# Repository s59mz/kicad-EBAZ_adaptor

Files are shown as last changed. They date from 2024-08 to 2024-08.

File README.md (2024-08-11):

# ebaz_adaptor
Adapter board from the EBAZ FPGA board to multiple Alinx modules and PMOD interfaces

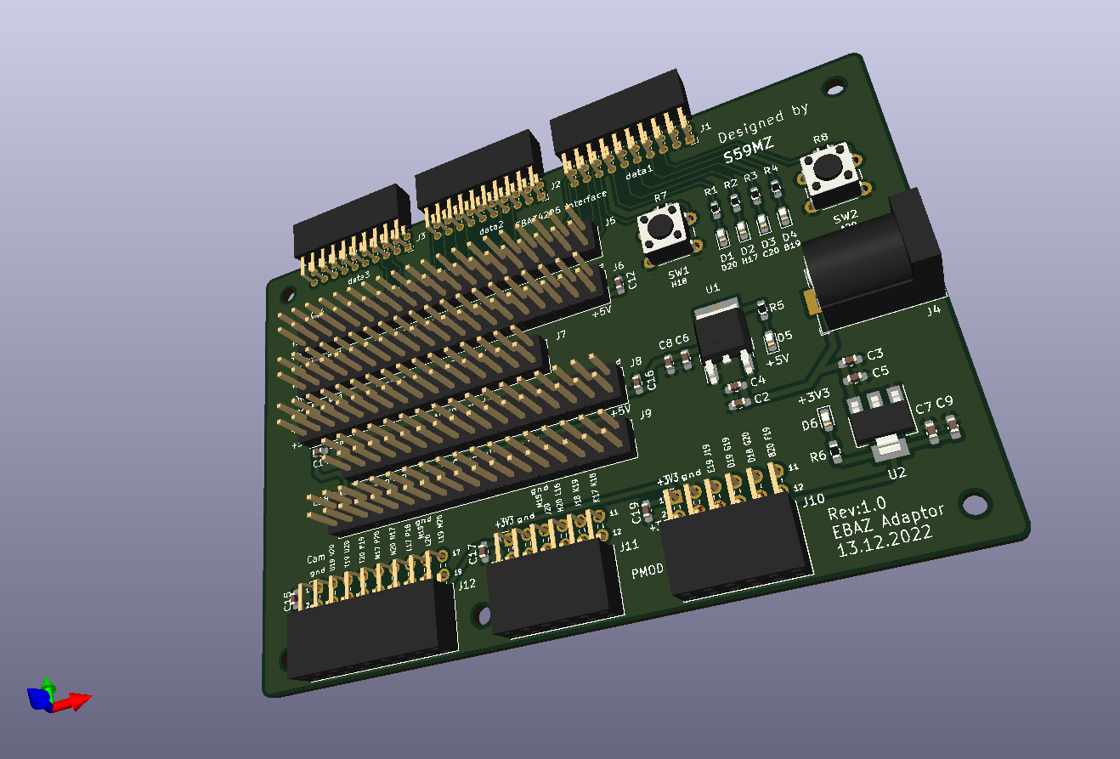
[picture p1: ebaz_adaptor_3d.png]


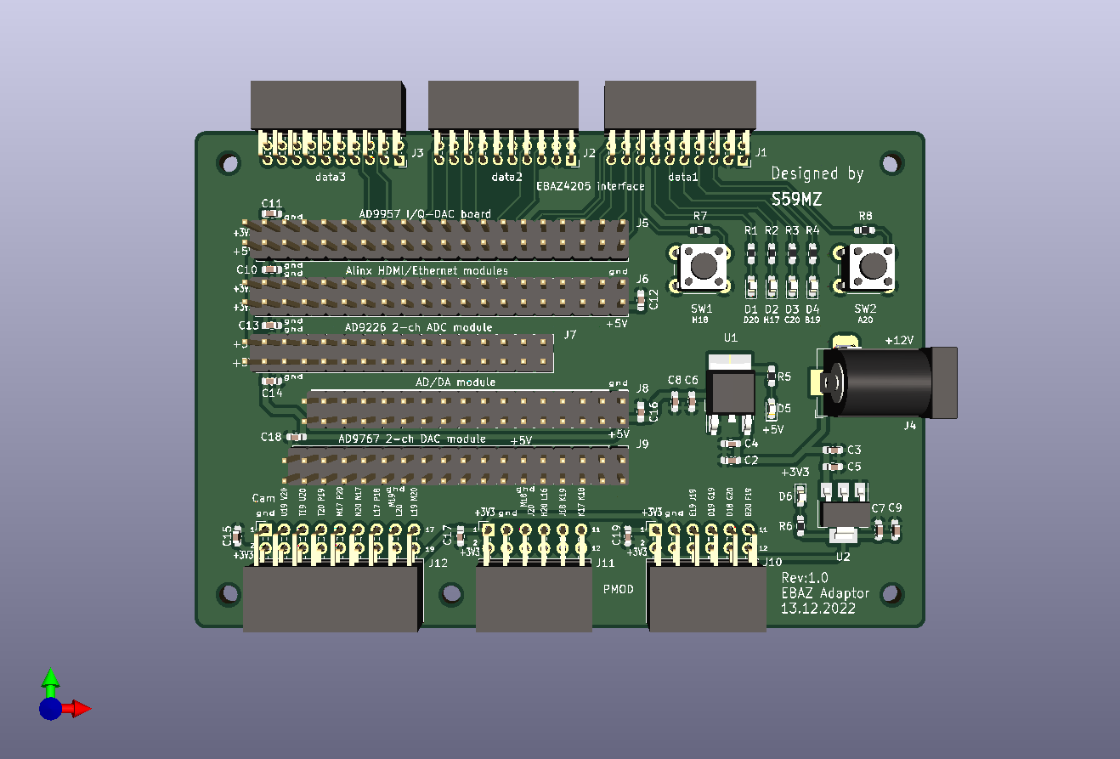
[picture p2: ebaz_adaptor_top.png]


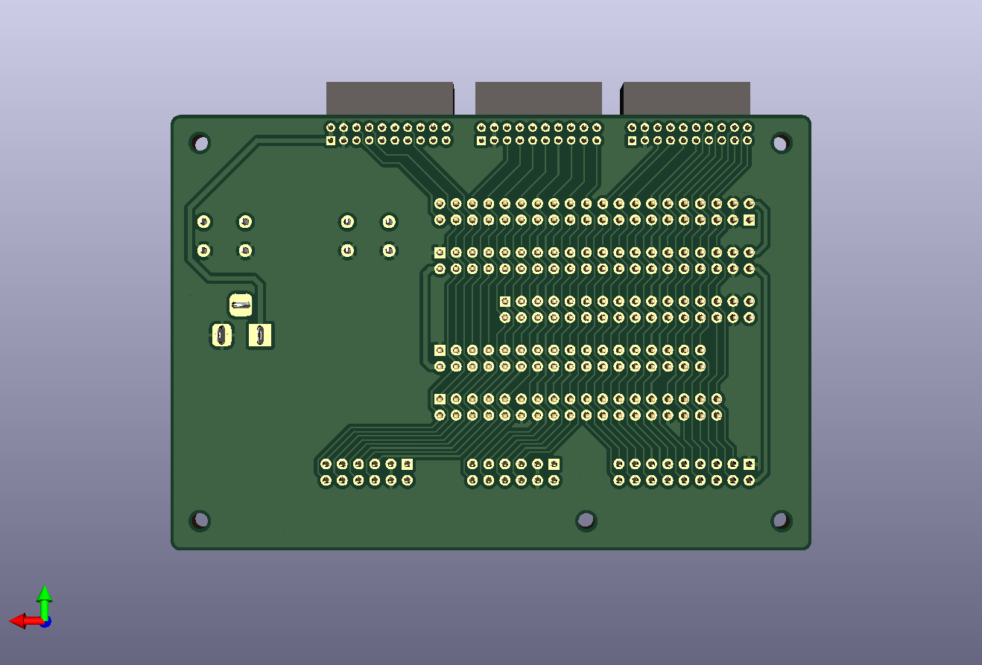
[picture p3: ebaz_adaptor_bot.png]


Schematic:
[ebaz_adaptor.pdf](ebaz_adaptor.pdf)

BOM:
[ebaz_adaptor.csv](ebaz_adaptor.csv)

Gerbers:
[gerbers.zip](https://github.com/s59mz/kicad-EBAZ_adaptor/raw/main/gerbers.zip)

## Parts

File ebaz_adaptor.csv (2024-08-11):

Comment | Designator | Footprint | LCSC
10u | C2,C3,C6,C7,C10,C11 | Capacitor_SMD:C_0603_1608Metric_Pad1.08x0.95mm_HandSolder
100n | C4,C5,C8,C9,C12,C13,C14,C15,C16,C17,C18,C19 | Capacitor_SMD:C_0603_1608Metric_Pad1.08x0.95mm_HandSolder
red | D1,D2,D3,D4,D5 | LED_SMD:LED_0603_1608Metric_Pad1.05x0.95mm_HandSolder
green | D6 | LED_SMD:LED_0603_1608Metric_Pad1.05x0.95mm_HandSolder
2.5 | H1,H2,H3,H4,H5 | MountingHole:MountingHole_2.5mm
data-1 | J1 | connectors:PinSocket_2x10_P2.00mm_Horizontal
pmod 1 | J10 | Connector_PinSocket_2.54mm:PinSocket_2x06_P2.54mm_Horizontal
pmod 2 | J11 | Connector_PinSocket_2.54mm:PinSocket_2x06_P2.54mm_Horizontal
camera | J12 | Connector_PinSocket_2.54mm:PinSocket_2x09_P2.54mm_Horizontal
data-2 | J2 | connectors:PinSocket_2x10_P2.00mm_Horizontal
data-3 | J3 | connectors:PinSocket_2x10_P2.00mm_Horizontal
+12V pwr | J4 | Connector_BarrelJack:BarrelJack_Horizontal
Z-Turn Extension | J5 | Connector_PinHeader_2.54mm:PinHeader_2x20_P2.54mm_Vertical
Alinx HDMI/ETH module | J6 | Connector_PinHeader_2.54mm:PinHeader_2x20_P2.54mm_Vertical
ADC module 2-ch | J7 | Connector_PinHeader_2.54mm:PinHeader_2x16_P2.54mm_Vertical
AD DA module | J8 | Connector_PinHeader_2.54mm:PinHeader_2x17_P2.54mm_Vertical
DAC module 2-ch | J9 | Connector_PinHeader_2.54mm:PinHeader_2x18_P2.54mm_Vertical
470E | R1,R2,R3,R4,R6 | Resistor_SMD:R_0603_1608Metric_Pad0.98x0.95mm_HandSolder
1k | R5,R7,R8 | Resistor_SMD:R_0603_1608Metric_Pad0.98x0.95mm_HandSolder
SW_Push | SW1,SW2 | Button_Switch_THT:SW_PUSH_6mm
AMS1117-5.0 | U1 | Package_TO_SOT_SMD:TO-252-2
AMS1117-3.3 | U2 | Package_TO_SOT_SMD:SOT-223-3_TabPin2

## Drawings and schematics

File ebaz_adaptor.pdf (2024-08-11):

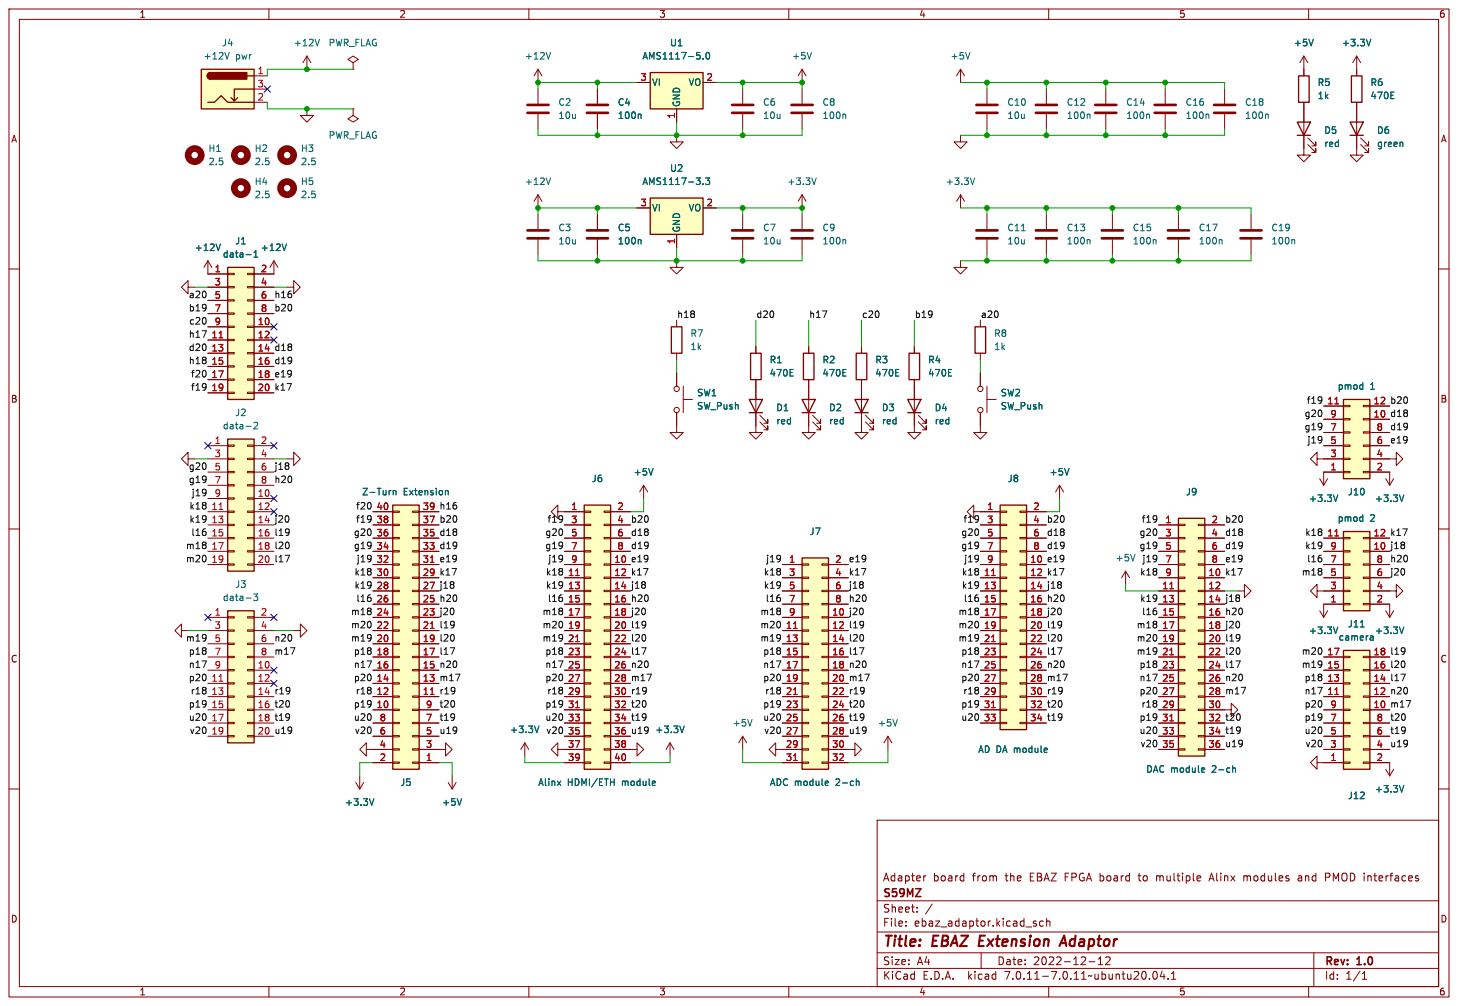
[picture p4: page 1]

J6 Alinx HDMI/ETH module

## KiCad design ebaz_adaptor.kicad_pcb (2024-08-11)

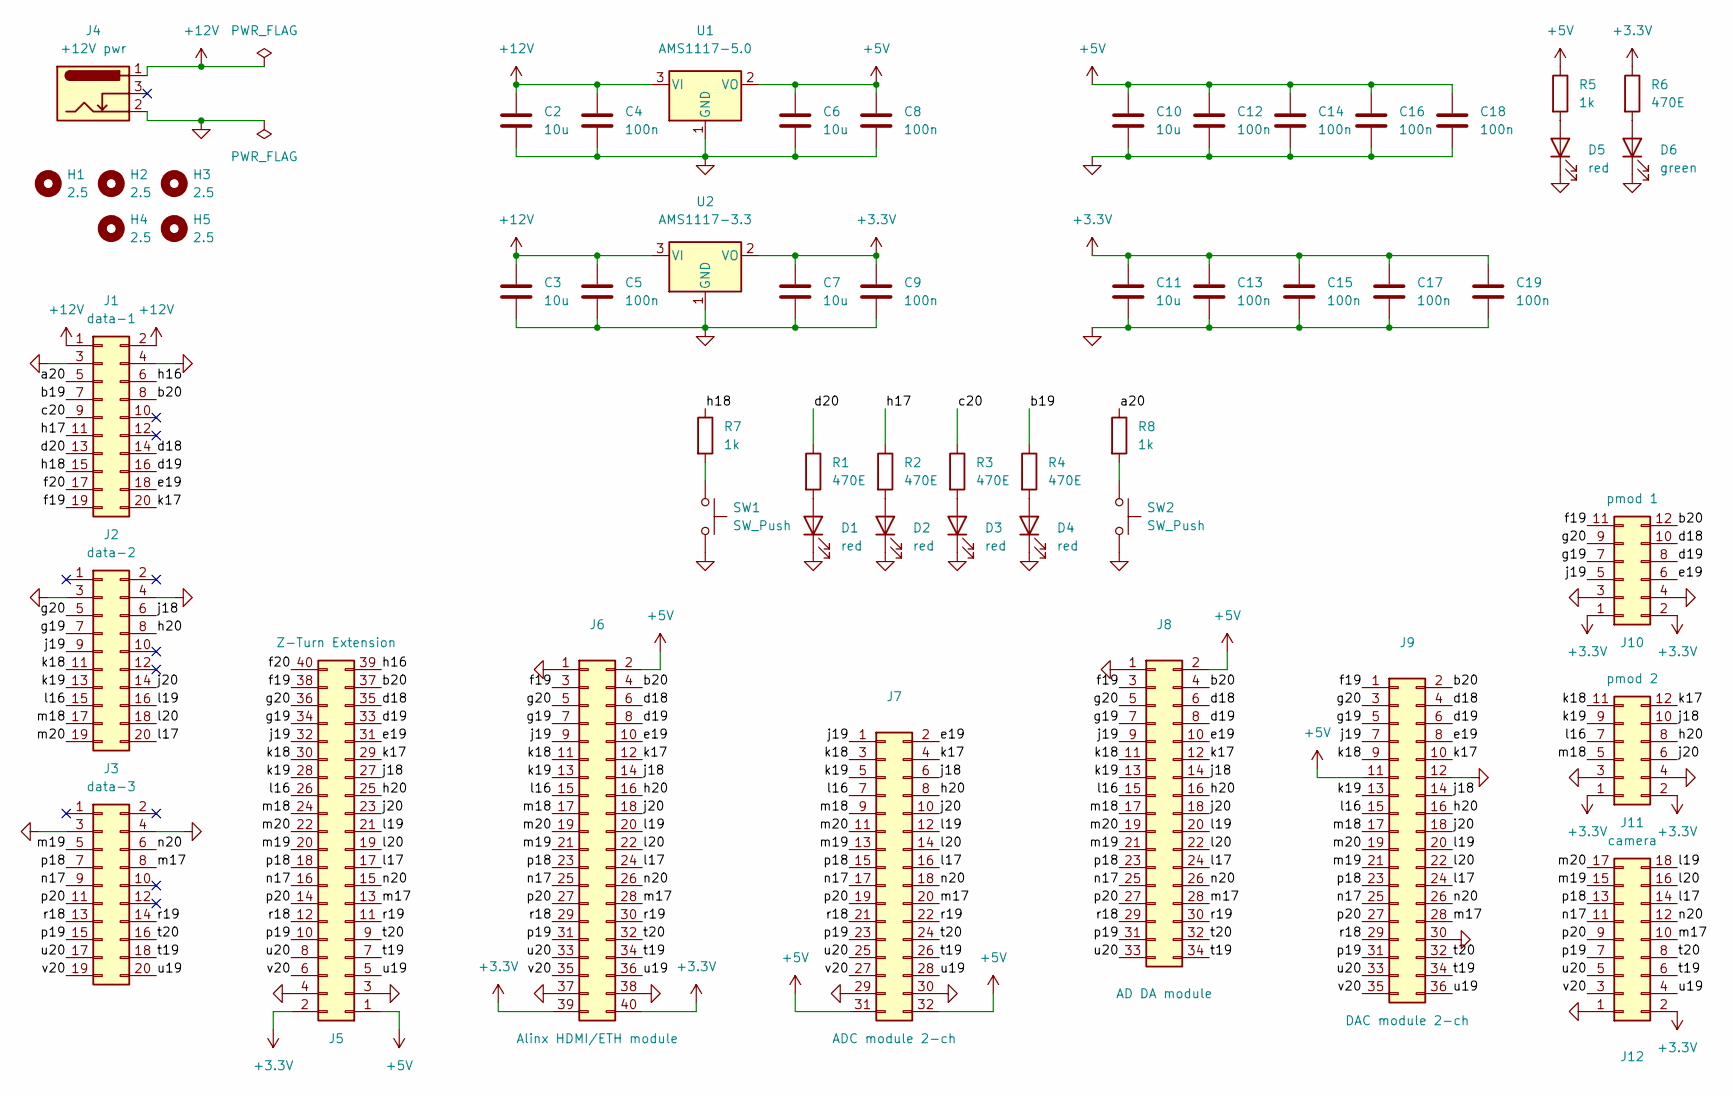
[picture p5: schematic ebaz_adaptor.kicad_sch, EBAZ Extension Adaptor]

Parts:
C2, C3, C6, C7, C10, C11: 10u; C_0603_1608Metric_Pad1.08x0.95mm_HandSolder
C4, C5, C8, C9, C12, C13, C14, C15, C16, C17, C18, C19: 100n; C_0603_1608Metric_Pad1.08x0.95mm_HandSolder
D1, D2, D3, D4, D5: red; LED_0603_1608Metric_Pad1.05x0.95mm_HandSolder
D6: green; LED_0603_1608Metric_Pad1.05x0.95mm_HandSolder
H1, H2, H3, H4, H5: 2.5; MountingHole_2.5mm
J1: data-1; PinSocket_2x10_P2.00mm_Horizontal
J2: data-2; PinSocket_2x10_P2.00mm_Horizontal
J3: data-3; PinSocket_2x10_P2.00mm_Horizontal
J4: +12V pwr; BarrelJack_Horizontal
J5: Z-Turn Extension; PinHeader_2x20_P2.54mm_Vertical
J6: Alinx HDMI/ETH module; PinHeader_2x20_P2.54mm_Vertical
J7: ADC module 2-ch; PinHeader_2x16_P2.54mm_Vertical
J8: AD DA module; PinHeader_2x17_P2.54mm_Vertical
J9: DAC module 2-ch; PinHeader_2x18_P2.54mm_Vertical
J10: pmod 1; PinSocket_2x06_P2.54mm_Horizontal
J11: pmod 2; PinSocket_2x06_P2.54mm_Horizontal
J12: camera; PinSocket_2x09_P2.54mm_Horizontal
R1, R2, R3, R4, R6: 470E; R_0603_1608Metric_Pad0.98x0.95mm_HandSolder
R5, R7, R8: 1k; R_0603_1608Metric_Pad0.98x0.95mm_HandSolder
SW1, SW2: SW_Push; SW_PUSH_6mm
U1: AMS1117-5.0; TO-252-2
U2: AMS1117-3.3; SOT-223-3_TabPin2

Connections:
+3.3V: C7.1, C9.1, C11.1, C13.1, C15.1, C17.1, C19.1, J5.2, J6.39, J6.40, J10.1, J10.2, J11.1, J11.2, J12.2, R6.1, U2.2 (VO)
+5V: C6.1, C8.1, C10.1, C12.1, C14.1, C16.1, C18.1, J5.1, J6.2, J7.31, J7.32, J8.2, J9.11, R5.1, U1.2 (VO)
+12V: C2.1, C3.1, C4.1, C5.1, J1.1, J1.2, J4.1, U1.3 (VI), U2.3 (VI)
/a20: J1.5, R8.1
/b19: J1.7, R4.1
/b20: J1.8, J5.37, J6.4, J8.4, J9.2, J10.12
/c20: J1.9, R3.1
/d18: J1.14, J5.35, J6.6, J8.6, J9.4, J10.10
/d19: J1.16, J5.33, J6.8, J8.8, J9.6, J10.8
/d20: J1.13, R1.1
/e19: J1.18, J5.31, J6.10, J7.2, J8.10, J9.8, J10.6
/f19: J1.19, J5.38, J6.3, J8.3, J9.1, J10.11
/f20: J1.17, J5.40
/g19: J2.7, J5.34, J6.7, J8.7, J9.5, J10.7
/g20: J2.5, J5.36, J6.5, J8.5, J9.3, J10.9
/h16: J1.6, J5.39
/h17: J1.11, R2.1
/h18: J1.15, R7.1
/h20: J2.8, J5.25, J6.16, J7.8, J8.16, J9.16, J11.8
/j18: J2.6, J5.27, J6.14, J7.6, J8.14, J9.14, J11.10
/j19: J2.9, J5.32, J6.9, J7.1, J8.9, J9.7, J10.5
/j20: J2.14, J5.23, J6.18, J7.10, J8.18, J9.18, J11.6
/k17: J1.20, J5.29, J6.12, J7.4, J8.12, J9.10, J11.12
/k18: J2.11, J5.30, J6.11, J7.3, J8.11, J9.9, J11.11
/k19: J2.13, J5.28, J6.13, J7.5, J8.13, J9.13, J11.9
/l16: J2.15, J5.26, J6.15, J7.7, J8.15, J9.15, J11.7
/l17: J2.20, J5.17, J6.24, J7.16, J8.24, J9.24, J12.14
/l19: J2.16, J5.21, J6.20, J7.12, J8.20, J9.20, J12.18
/l20: J2.18, J5.19, J6.22, J7.14, J8.22, J9.22, J12.16
/m17: J3.8, J5.13, J6.28, J7.20, J8.28, J9.28, J12.10
/m18: J2.17, J5.24, J6.17, J7.9, J8.17, J9.17, J11.5
/m19: J3.5, J5.20, J6.21, J7.13, J8.21, J9.21, J12.15
/m20: J2.19, J5.22, J6.19, J7.11, J8.19, J9.19, J12.17
/n17: J3.9, J5.16, J6.25, J7.17, J8.25, J9.25, J12.11
/n20: J3.6, J5.15, J6.26, J7.18, J8.26, J9.26, J12.12
/p18: J3.7, J5.18, J6.23, J7.15, J8.23, J9.23, J12.13
/p19: J3.15, J5.10, J6.31, J7.23, J8.31, J9.31, J12.7
/p20: J3.11, J5.14, J6.27, J7.19, J8.27, J9.27, J12.9
/r18: J3.13, J5.12, J6.29, J7.21, J8.29, J9.29
/r19: J3.14, J5.11, J6.30, J7.22, J8.30
/t19: J3.18, J5.7, J6.34, J7.26, J8.34, J9.34, J12.6
/t20: J3.16, J5.9, J6.32, J7.24, J8.32, J9.32, J12.8
/u19: J3.20, J5.5, J6.36, J7.28, J9.36, J12.4
/u20: J3.17, J5.8, J6.33, J7.25, J8.33, J9.33, J12.5
/v20: J3.19, J5.6, J6.35, J7.27, J9.35, J12.3
GND: C2.2, C3.2, C4.2, C5.2, C6.2, C7.2, C8.2, C9.2, C10.2, C11.2, C12.2, C13.2, C14.2, C15.2, C16.2, C17.2, C18.2, C19.2, D1.1 (K), D2.1 (K), D3.1 (K), D4.1 (K), D5.1 (K), D6.1 (K), J1.3, J1.4, J2.3, J2.4, J3.3, J3.4, J4.2, J5.3, J5.4, J6.1, J6.37, J6.38, J7.29, J7.30, J8.1, J9.12, J9.30, J10.3, J10.4, J11.3, J11.4, J12.1, SW1.2, SW2.2, U1.1 (GND), U2.1 (GND)
unnamed: D1.2 (A), R1.2
unnamed: D2.2 (A), R2.2
unnamed: D3.2 (A), R3.2
unnamed: D4.2 (A), R4.2
unnamed: D5.2 (A), R5.2
unnamed: D6.2 (A), R6.2
unnamed: R7.2, SW1.1
unnamed: R8.2, SW2.1

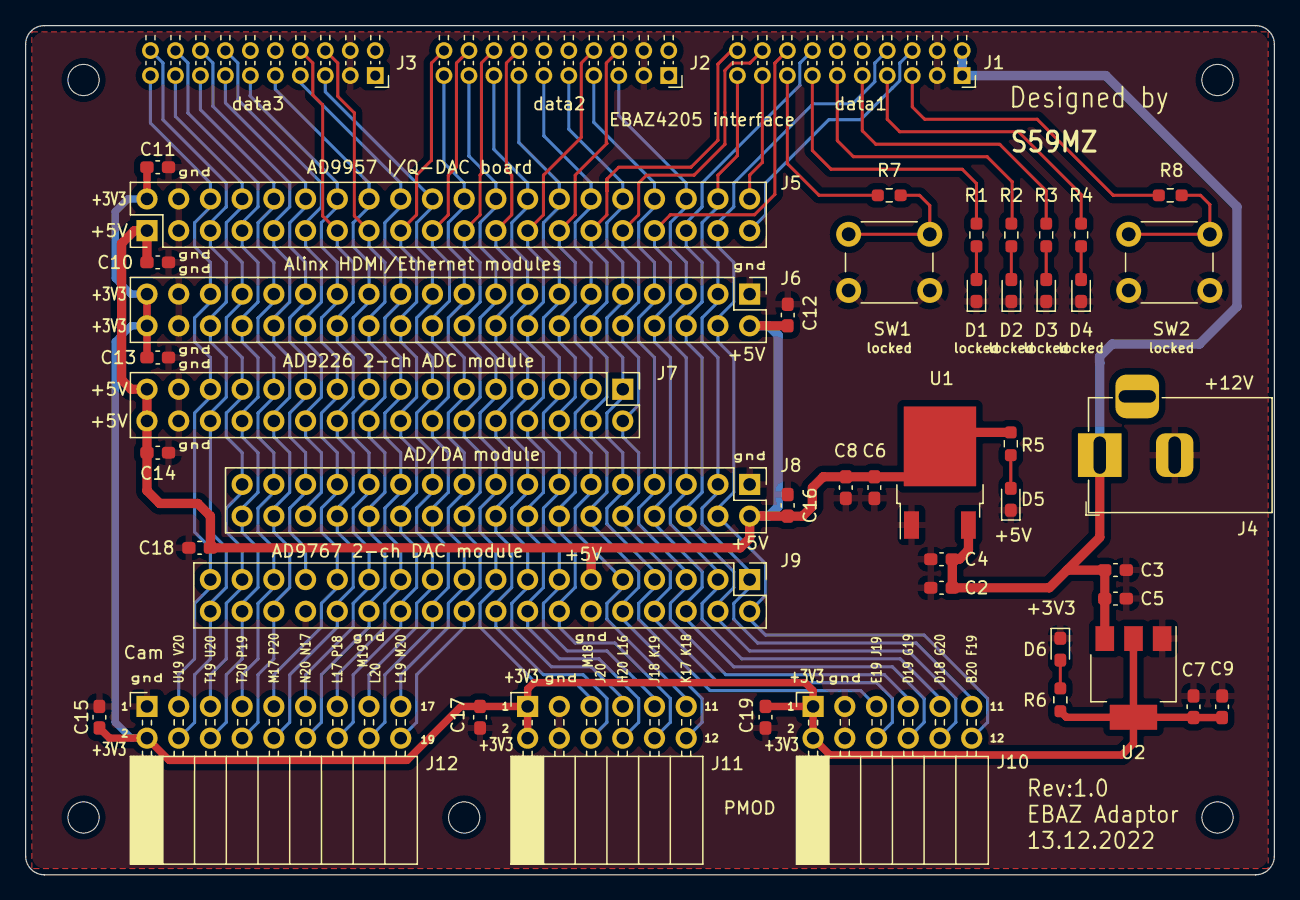
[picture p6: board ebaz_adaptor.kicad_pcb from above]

Board: 2 copper layers, 100.0 x 68.0 mm, 53 parts (0 on the bottom side), 54 nets.
